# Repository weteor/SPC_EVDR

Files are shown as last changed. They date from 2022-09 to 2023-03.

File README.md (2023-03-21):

# SPC EVDR
38 key orthogonl keyboard w/ offset spacebar

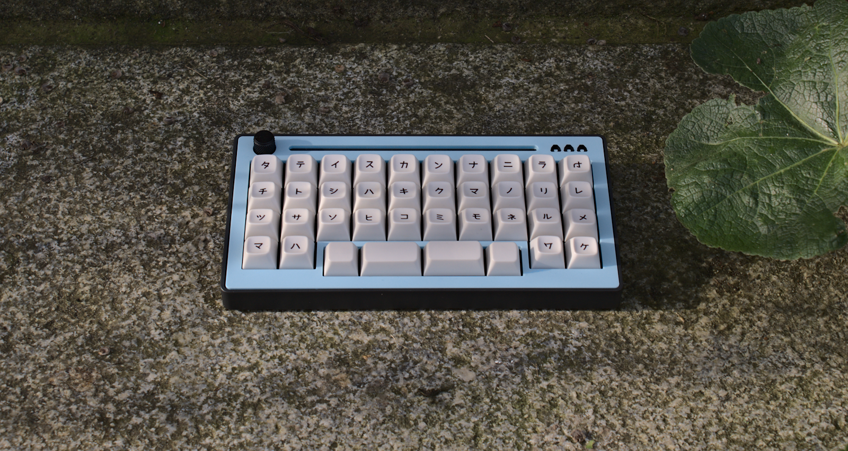
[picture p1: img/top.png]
top


## Features

- MX w/ hotswap
- encoder (12 mm knob diameter)
- OLED
- Bluetooth and USB connection
- case with optional acrylic accents
- case files are supplied (stl, dxf, as well as the freecad files)
- ZMK firmware support ( on Seeed Xiao SAMD21 or Seeed Xiao BLE )
- QMK firmware support ( on Seeed Xiao RP2040 )
- completely open source, permissive license

## Want one?
All production files you need to build your own board can be found [here](./prod).

Please see the [build instruction](prod/build_guide.md) for a more detailed listing of all things needed.

Gerber files as well as files needed for 3d printing are provided. Please note that the case design that supports the acryl layin may not be SLN printable. Please print them either in resin or nylon. I've used JLCPCBs printing service (black resin) and it turned out very good, so maybe take a look at that option.

### firmware 
The SPC EVDR uses ZMK firmware.

If you prefer the github workflow, you can find the zmk config [here](https://github.com/weteor/SPC_EVDR-Config).

## the rest
Everything in this repository is free to use however you might see fit. If you want to support me and my projects, please consider linking back to this repository if you build/change/use anything. 

If you would like to send me a tip, you could do it [here](https://ko-fi.com/weteor) (Please don't feel like you have to).

### some more images
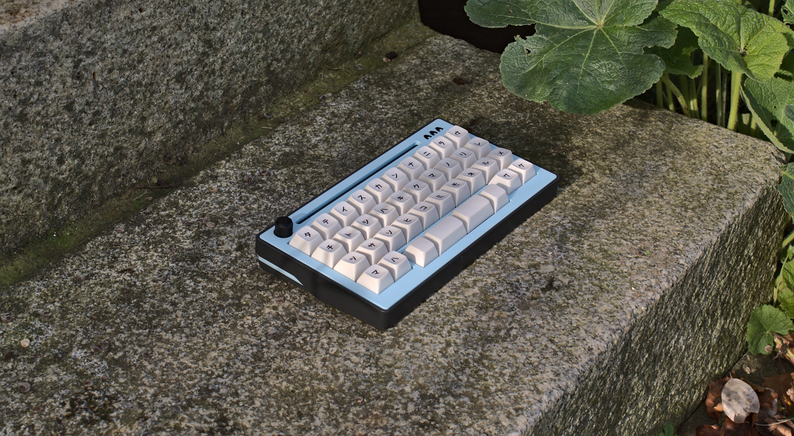
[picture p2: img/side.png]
side


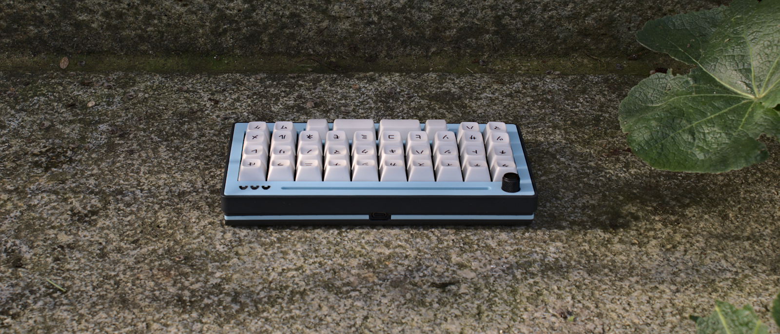
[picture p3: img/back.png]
back


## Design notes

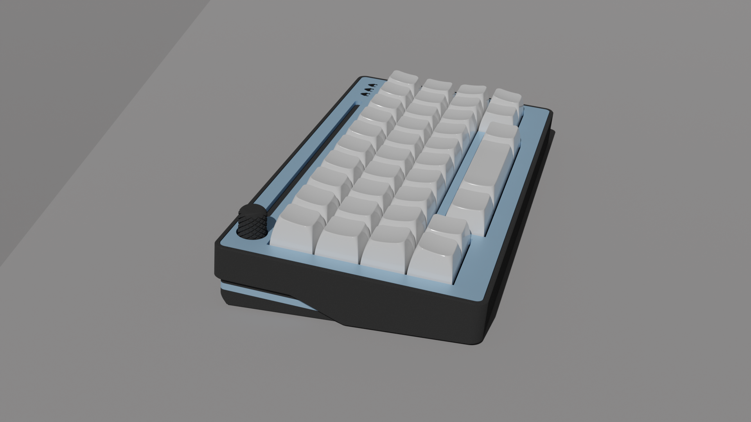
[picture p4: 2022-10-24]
img/side_knob.png

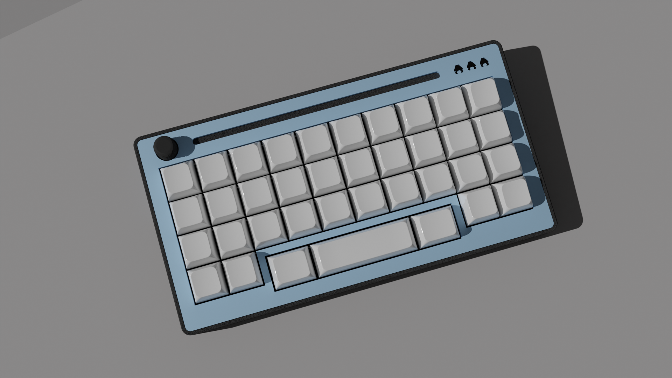
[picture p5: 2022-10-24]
img/top_knob.png

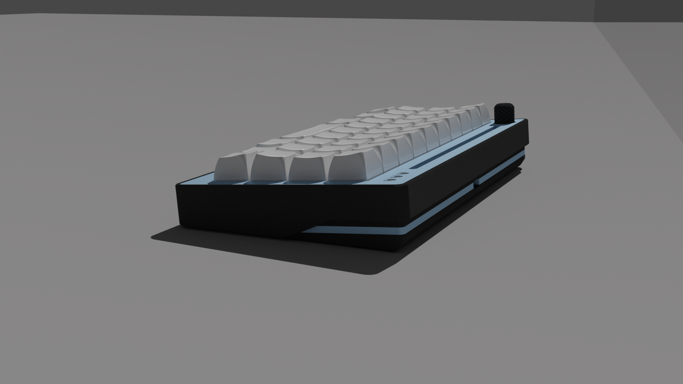
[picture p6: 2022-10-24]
img/backRight.png

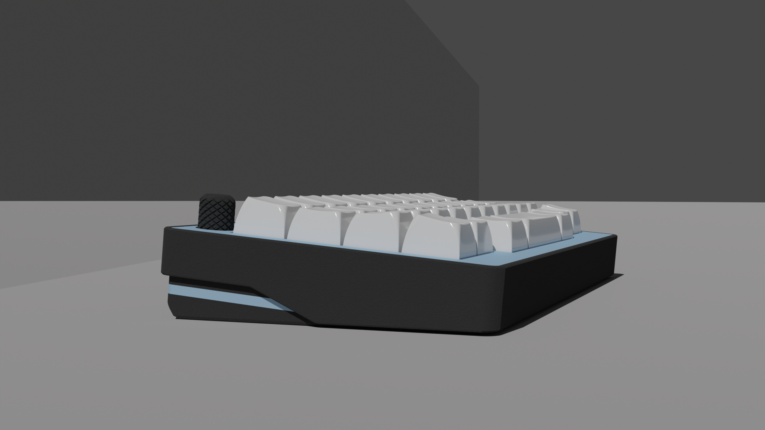
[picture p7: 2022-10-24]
img/side_knob_1.png

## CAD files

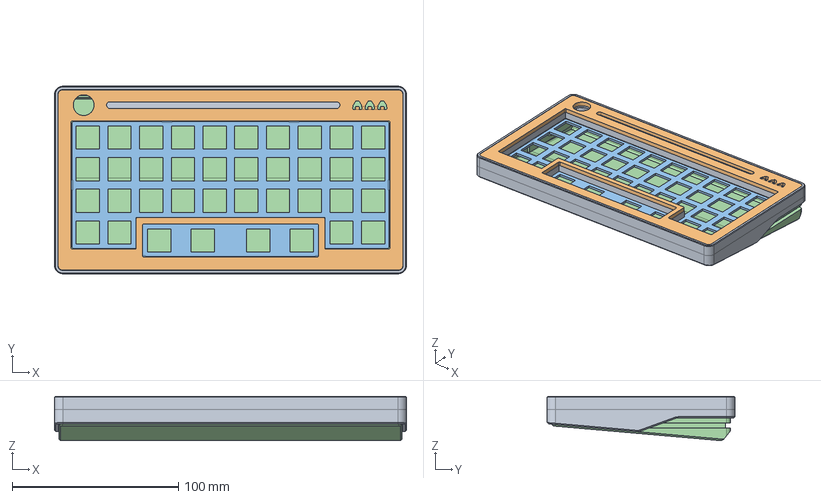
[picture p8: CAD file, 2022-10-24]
cad/case.FCStd
211.5 x 112.7 x 26.6 mm
Case
Acryl
Plate
bottomCase

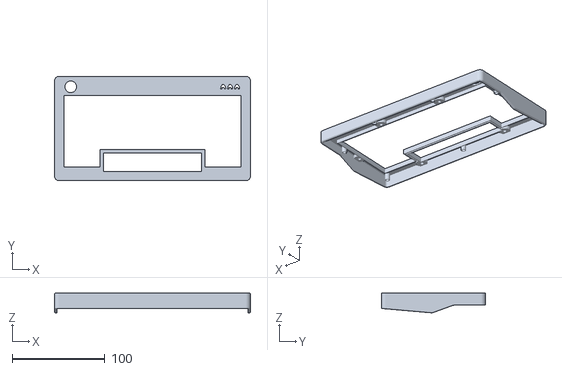
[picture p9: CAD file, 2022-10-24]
prod/Case/case_top_with_insert.stl
211.5 x 112.7 x 21.2

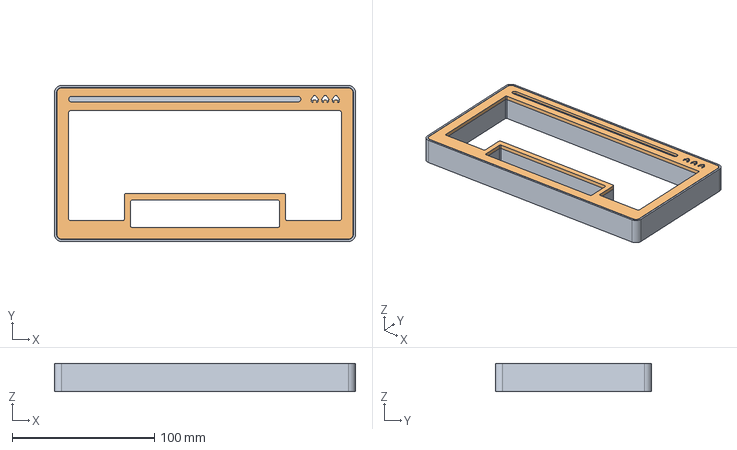
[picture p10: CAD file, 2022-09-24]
cad/platecase.FCStd
211.5 x 109.7 x 20.0 mm
Case

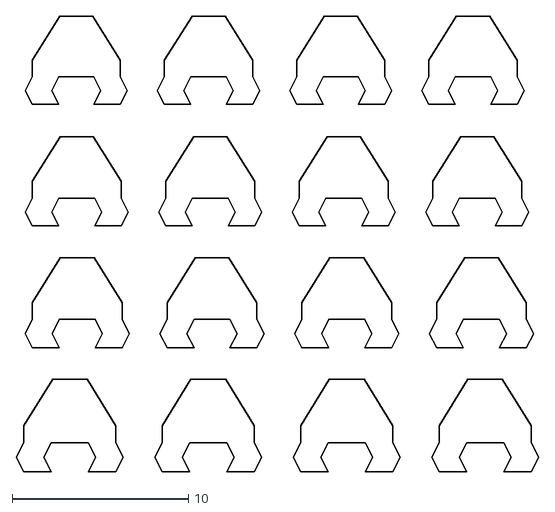
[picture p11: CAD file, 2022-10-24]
prod/Case/case_inveader_cover_cut.dxf
29.6 x 25.8

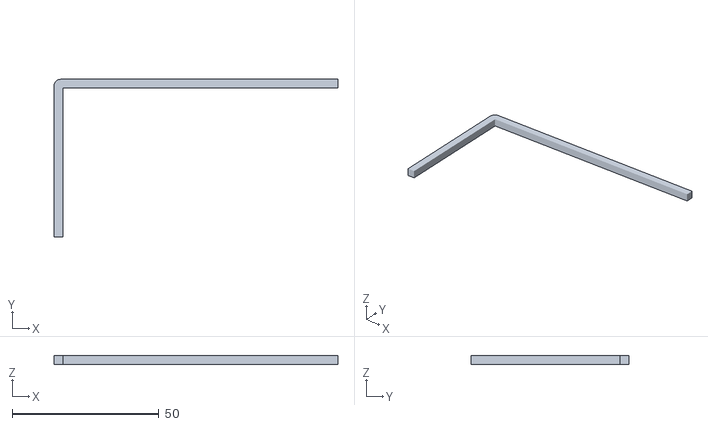
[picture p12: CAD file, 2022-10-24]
prod/Case/case_bottom_insert_left_printed.stl
96.8 x 53.7 x 3.00

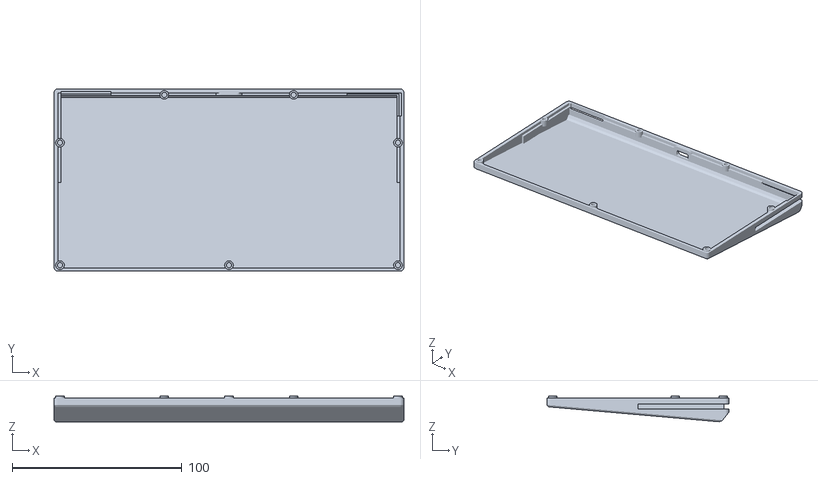
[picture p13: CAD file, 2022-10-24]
prod/Case/case_bottom.stl
206.2 x 107.4 x 15.1

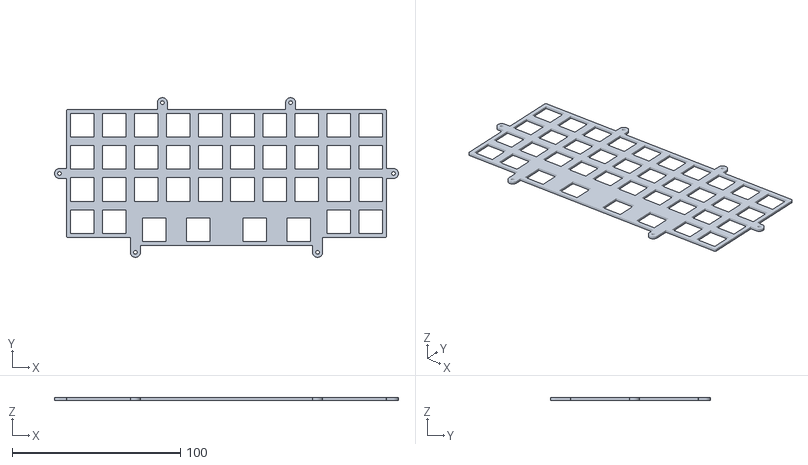
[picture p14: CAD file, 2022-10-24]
prod/Case/plate_1u_1.75u_1.75u_1u.stl
204.5 x 95.0 x 1.60

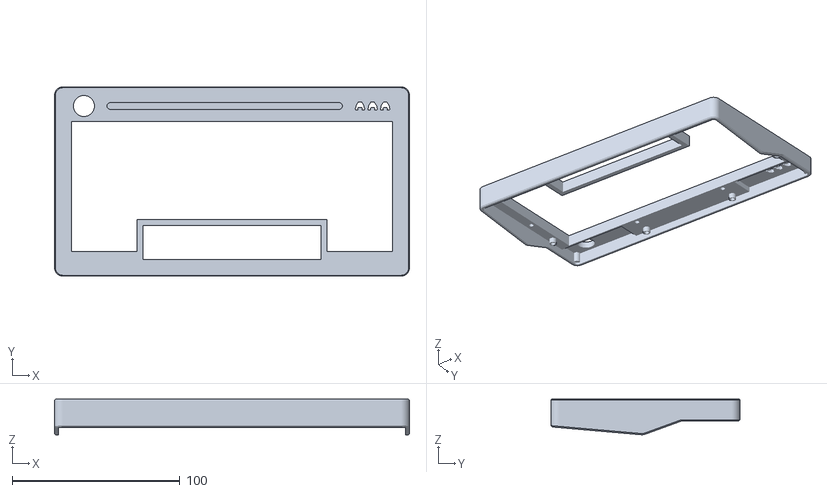
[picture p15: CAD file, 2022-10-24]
prod/Case/case_top_no_insert.stl
211.5 x 112.7 x 21.2

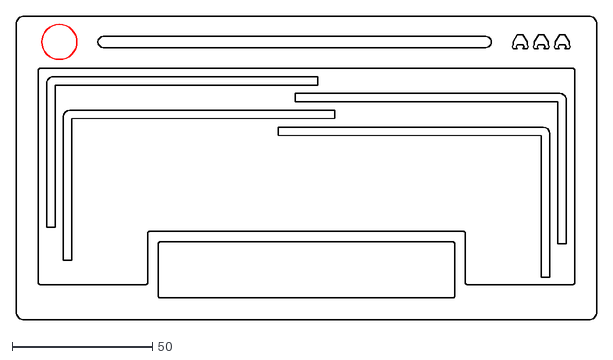
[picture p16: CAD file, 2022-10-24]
prod/Case/case_top_bottom_inserts_cut.dxf
207.2 x 108.4

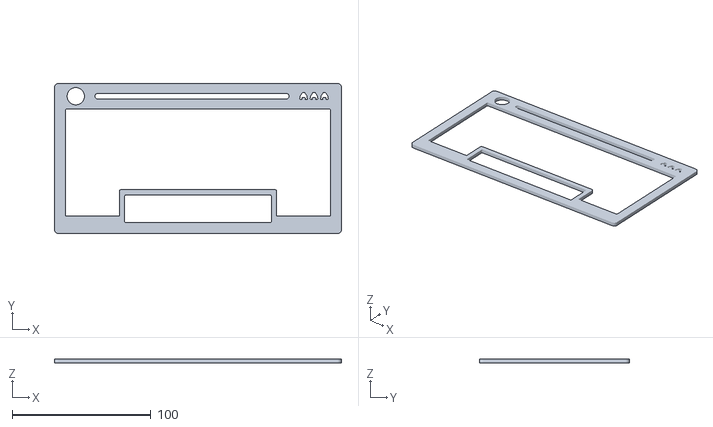
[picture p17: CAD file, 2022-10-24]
prod/Case/case_top_insert_printed.stl
207.2 x 108.4 x 3.00

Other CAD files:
prod/Case/case_bottom_insert_right_printed.stl

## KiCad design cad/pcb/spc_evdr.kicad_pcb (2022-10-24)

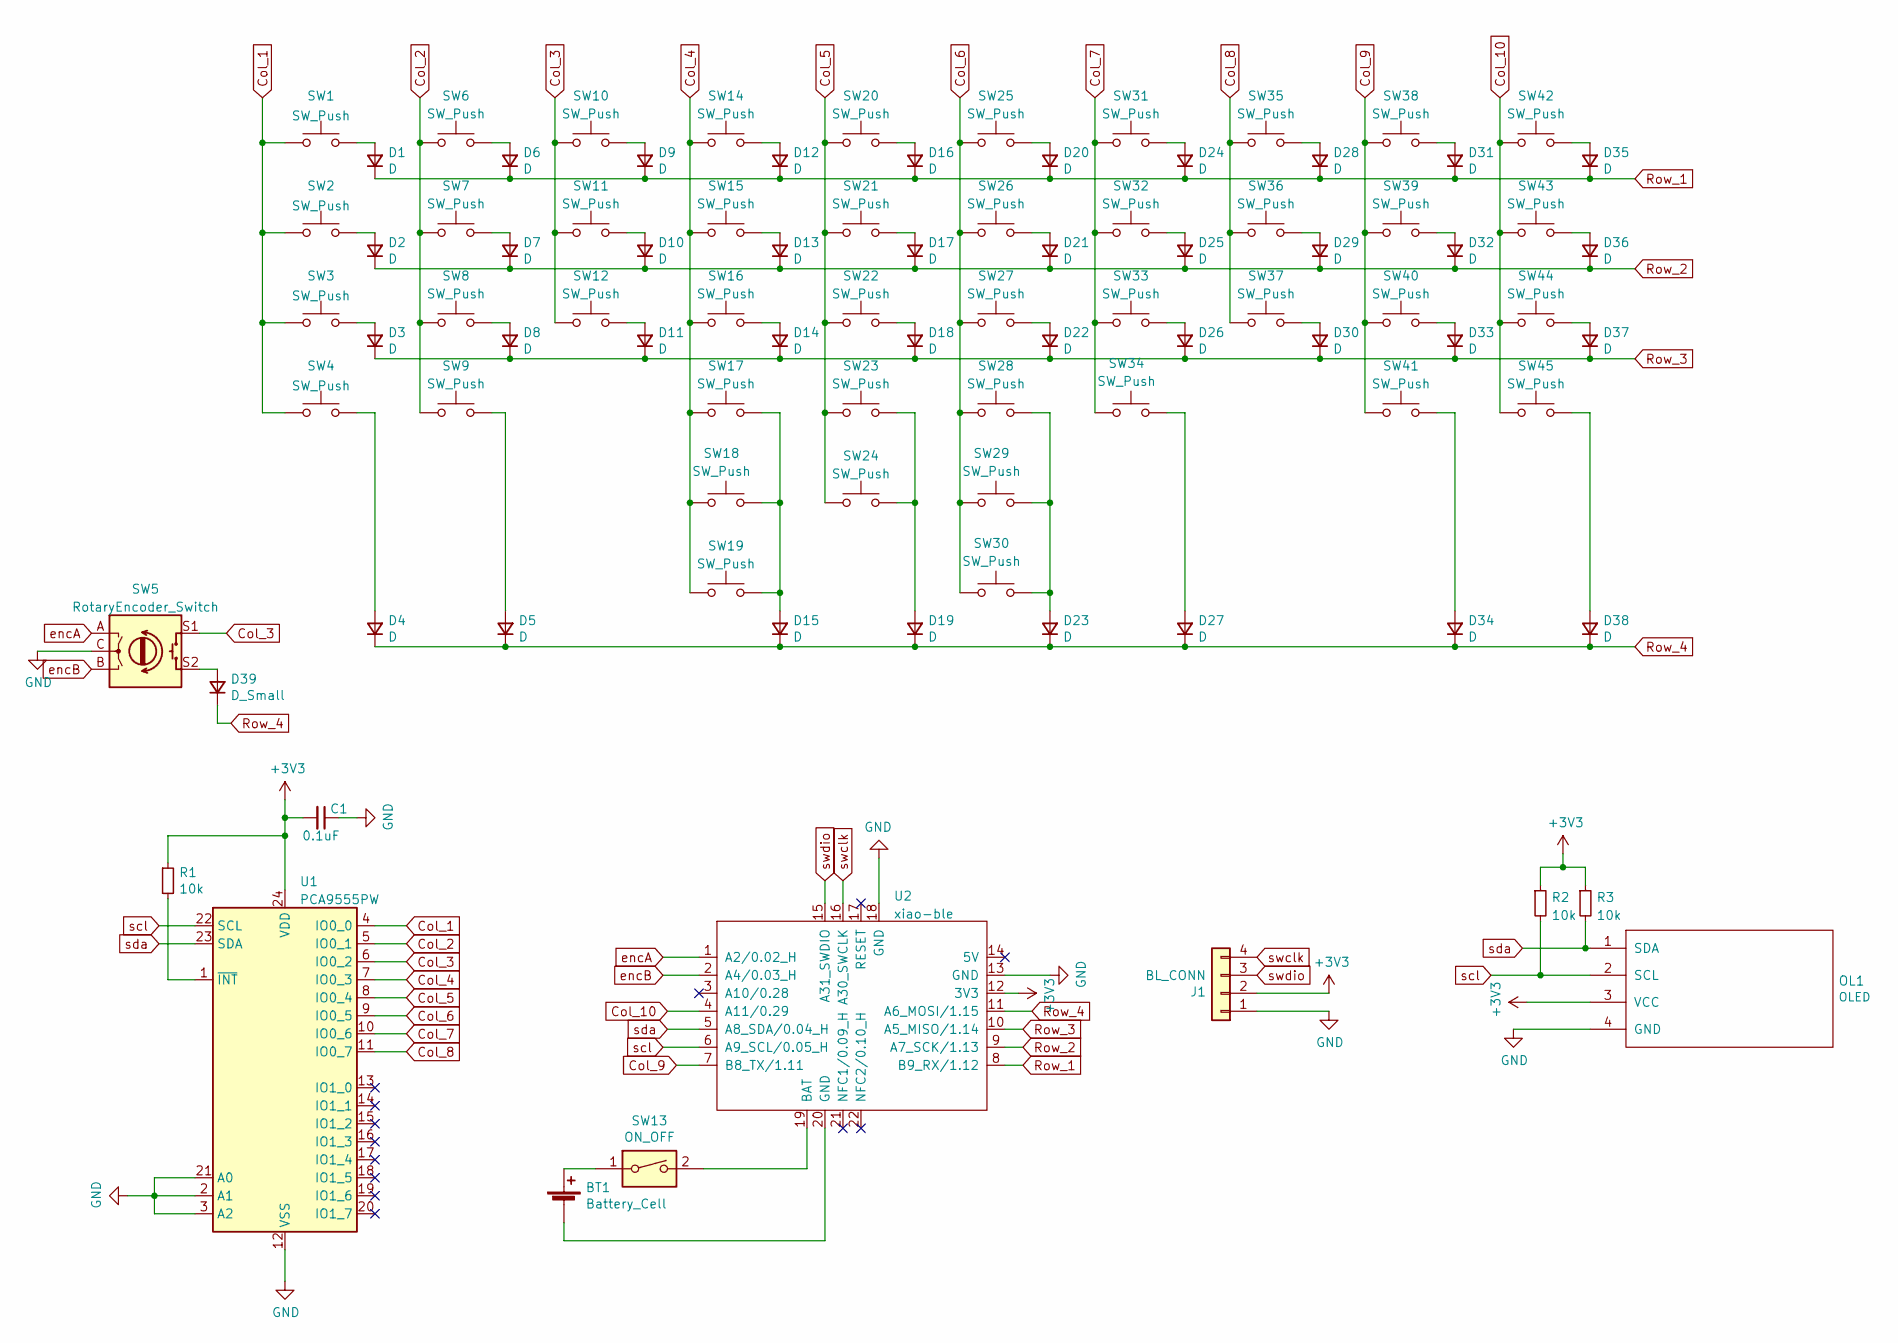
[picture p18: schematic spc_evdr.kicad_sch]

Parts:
BT1: Battery_Cell; Molex_PicoBlade_53048-0210_1x02_P1.25mm_Horizontal
C1: 0.1uF; C_0805_2012Metric
D1, D2, D3, D4, D5, D6, D7, D8, D9, D10, D11, D12, D13, D14, D15, D16, D17, D18, D19, D20, D21, D22, D23, D24, D25, D26, D27, D28, D29, D30, D31, D32, D33, D34, D35, D36, D37, D38: D; D_SOD-123
D39: D_Small; D_SOD-123
J1: BL_CONN; PinHeader_1x04_P2.54mm_Vertical
OL1: OLED; OLED_1side
R1, R2, R3: 10k; R_0805_2012Metric
SW1, SW2, SW3, SW4, SW6, SW7, SW8, SW9, SW10, SW11, SW12, SW14, SW15, SW16, SW17, SW20, SW21, SW22, SW25, SW26, SW27, SW31, SW32, SW33, SW34, SW35, SW36, SW37, SW38, SW39, SW40, SW41, SW42, SW43, SW44, SW45: SW_Push; CherryMX_Hotswap
SW5: RotaryEncoder_Switch; RotaryEncoder_Alps_EC11E-Switch_Vertical_H20mm
SW13: ON_OFF; switch_MSK-12C02_smd
SW18, SW29: SW_Push; CherryMX_Hotswap_1.25u
SW19, SW30: SW_Push; CherryMX_Hotswap_2.25u_stabs
SW23, SW28: SW_Push; CherryMX_Hotswap_1.75u
SW24: SW_Push; CherryMX_Hotswap_3u_stabs
U1: PCA9555PW; TSSOP-24_4.4x7.8mm_P0.65mm
U2: xiao-ble; xiao-ble-smd-cutout

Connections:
+3V3: C1.2, J1.2, OL1.3 (VCC), R1.1, R2.1, R3.1, U1.24 (VDD), U2.12 (3V3)
Col_1: SW1.1, SW2.1, SW3.1, SW4.1, U1.4 (IO0_0)
Col_2: SW6.1, SW7.1, SW8.1, SW9.1, U1.5 (IO0_1)
Col_3: SW5.S1, SW10.1, SW11.1, SW12.1, U1.6 (IO0_2)
Col_4: SW14.1, SW15.1, SW16.1, SW17.1, SW18.1, SW19.1, U1.7 (IO0_3)
Col_5: SW20.1, SW21.1, SW22.1, SW23.1, SW24.1, U1.8 (IO0_4)
Col_6: SW25.1, SW26.1, SW27.1, SW28.1, SW29.1, SW30.1, U1.9 (IO0_5)
Col_7: SW31.1, SW32.1, SW33.1, SW34.1, U1.10 (IO0_6)
Col_8: SW35.1, SW36.1, SW37.1, U1.11 (IO0_7)
Col_9: SW38.1, SW39.1, SW40.1, SW41.1, U2.7 (B8_TX/1.11)
Col_10: SW42.1, SW43.1, SW44.1, SW45.1, U2.4 (A11/0.29)
GND: C1.1, J1.1, OL1.4 (GND), SW5.C, U1.2 (A1), U1.3 (A2), U1.12 (VSS), U1.21 (A0), U2.13 (GND), U2.18 (GND)
unnamed: BT1.1 (+), SW13.1
unnamed: BT1.2 (-), U2.20 (GND)
unnamed: D1.2 (A), SW1.2
unnamed: D2.2 (A), SW2.2
unnamed: D3.2 (A), SW3.2
unnamed: D4.2 (A), SW4.2
unnamed: D5.2 (A), SW9.2
unnamed: D6.2 (A), SW6.2
unnamed: D7.2 (A), SW7.2
unnamed: D8.2 (A), SW8.2
unnamed: D9.2 (A), SW10.2
unnamed: D10.2 (A), SW11.2
unnamed: D11.2 (A), SW12.2
unnamed: D12.2 (A), SW14.2
unnamed: D13.2 (A), SW15.2
unnamed: D14.2 (A), SW16.2
unnamed: D15.2 (A), SW17.2, SW18.2, SW19.2
unnamed: D16.2 (A), SW20.2
unnamed: D17.2 (A), SW21.2
unnamed: D18.2 (A), SW22.2
unnamed: D19.2 (A), SW23.2, SW24.2
unnamed: D20.2 (A), SW25.2
unnamed: D21.2 (A), SW26.2
unnamed: D22.2 (A), SW27.2
unnamed: D23.2 (A), SW28.2, SW29.2, SW30.2
unnamed: D24.2 (A), SW31.2
unnamed: D25.2 (A), SW32.2
unnamed: D26.2 (A), SW33.2
unnamed: D27.2 (A), SW34.2
unnamed: D28.2 (A), SW35.2
unnamed: D29.2 (A), SW36.2
unnamed: D30.2 (A), SW37.2
unnamed: D31.2 (A), SW38.2
unnamed: D32.2 (A), SW39.2
unnamed: D33.2 (A), SW40.2
unnamed: D34.2 (A), SW41.2
unnamed: D35.2 (A), SW42.2
unnamed: D36.2 (A), SW43.2
unnamed: D37.2 (A), SW44.2
unnamed: D38.2 (A), SW45.2
unnamed: D39.2 (A), SW5.S2
unnamed: R1.2, U1.1 (~INT)
unnamed: SW13.2, U2.19 (BAT)
Row_1: D1.1 (K), D6.1 (K), D9.1 (K), D12.1 (K), D16.1 (K), D20.1 (K), D24.1 (K), D28.1 (K), D31.1 (K), D35.1 (K), U2.8 (B9_RX/1.12)
Row_2: D2.1 (K), D7.1 (K), D10.1 (K), D13.1 (K), D17.1 (K), D21.1 (K), D25.1 (K), D29.1 (K), D32.1 (K), D36.1 (K), U2.9 (A7_SCK/1.13)
Row_3: D3.1 (K), D8.1 (K), D11.1 (K), D14.1 (K), D18.1 (K), D22.1 (K), D26.1 (K), D30.1 (K), D33.1 (K), D37.1 (K), U2.10 (A5_MISO/1.14)
Row_4: D4.1 (K), D5.1 (K), D15.1 (K), D19.1 (K), D23.1 (K), D27.1 (K), D34.1 (K), D38.1 (K), D39.1 (K), U2.11 (A6_MOSI/1.15)
encA: SW5.A, U2.1 (A2/0.02_H)
encB: SW5.B, U2.2 (A4/0.03_H)
scl: OL1.2 (SCL), R2.2, U1.22 (SCL), U2.6 (A9_SCL/0.05_H)
sda: OL1.1 (SDA), R3.2, U1.23 (SDA), U2.5 (A8_SDA/0.04_H)
swclk: J1.4, U2.16 (A30_SWCLK)
swdio: J1.3, U2.15 (A31_SWDIO)

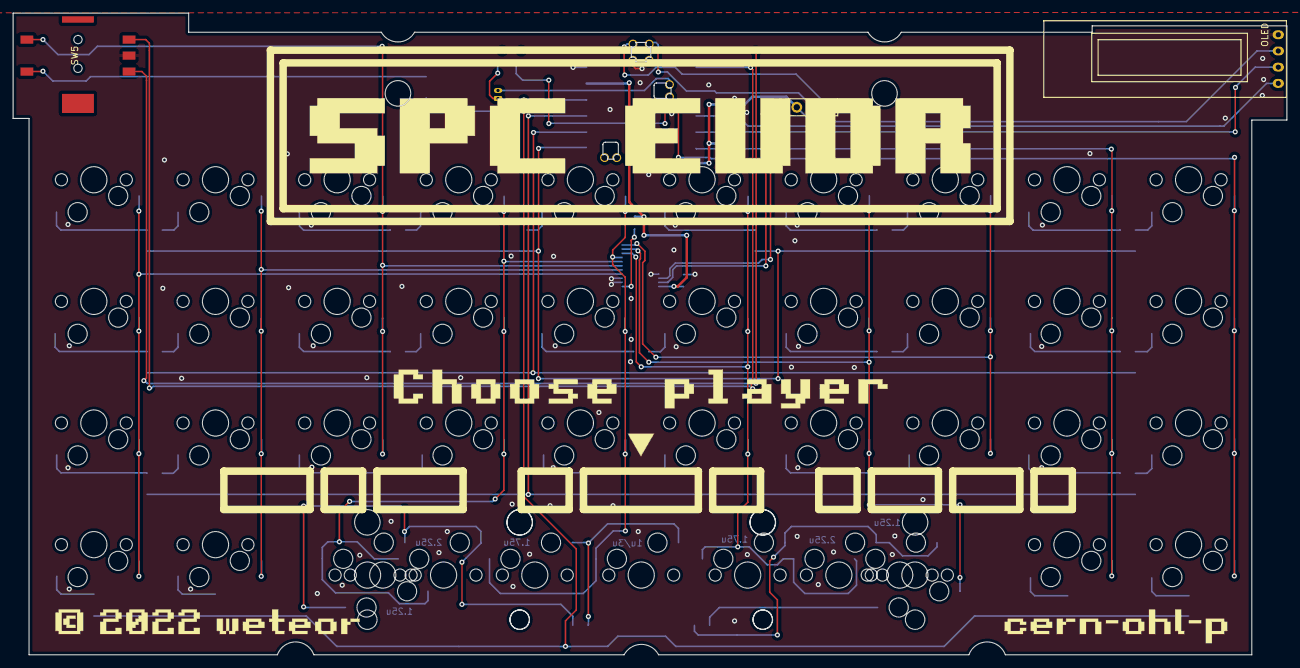
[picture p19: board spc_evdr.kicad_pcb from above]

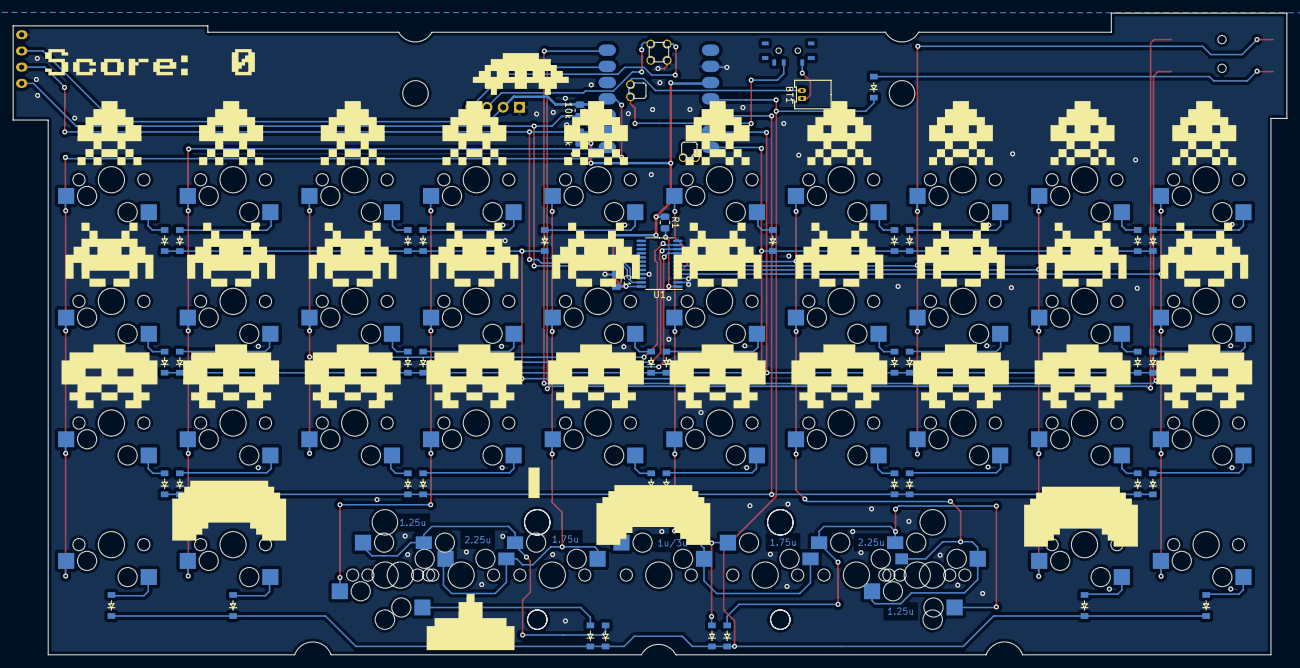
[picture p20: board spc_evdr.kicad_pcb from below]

Board: 2 copper layers, 199.5 x 100.5 mm, 93 parts (47 on the bottom side), 65 nets.

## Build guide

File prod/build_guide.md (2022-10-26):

# build instructions

## what do you need?

#### parts
| # | name | comments |
|---|---|---|
| 1 | main PCB | [gerber files](PCB) |
| 1 | Seeed Xiao (optional BLE) | Controller board |
| 3 | R - 0805 - 10k | resistor |
| 1 | C - 0805 - 100nF | capacitor |
| 1 | PCA9555PW | IO Expander |
| 38 | 1N4148 - SOD-123 | diodes |
| 38-41 | HS Sockets | MX hotswap sockets |
| 1 | ec11 12mm | encoder |
| 1 | 0.91'' 128x32px | OLED module |
| 1 | MSK-12C02 | power switch |
| 1 | JST GSH 1.25mm pitch | battery connector, 2pin (optional) |
| 1 | 3.7V LiPo | battery (optional) |
| 1 | case top | [case files](prod/case) |
| 1 | case botom | [case files](prod/case) |
| 1 | acryl inserts | [case files](prod/case) optional |
| 6 | heat inserts m2 | |
| 6 | M2 screws - 6mm | |
| 14 | magnets | 3x3 cylindrical N35 |
| 38 | switches | MX |
| | keycaps | |

#### tools
- soldering iron
- 
## build 
### pcb
- connect the Xiao, enter bootloader by double clicking the reset button, flash firmware and check if it is recognized correctly.
- solder the Xiao to the pcb
- solder IO expander, diodes, capacitor and resistors to the pcb.
- check if all switches work by shorting the pads.
- If everything works, solder everything except the OLED to the pcb

### case
- add heat inserts (either by melting them in, or file the hole a bit larger and just press them in)
- try if magnets fit the holes tightly. Add a bit of superglue if they don't stay in place. Make sure the polarity is correct!
- insert some switches to the plate edges so the pcb stays in place. Add the OLED, don't solder just yet. Alignt the plate and check if the OLED is aligned to the invader cutouts. You should be able to activate the OLED without soldering it if you angle it a bit. If it is not aligned, use some sharp/flat knife to loose the display a bit from it's pcb and reposition it.
- fix the plate with a few screws, the oled should rest on the top case, solder the OLED.
- add remaining switches
- screw in the plate
- put together both case parts.
- (optional) add acryl parts. If they don't stay in place use some double sided tape and/or superglue to keep them in place

ENJOY

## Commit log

2022-09-23 add mockup case and plate
    [platecase.FCStd]
2022-09-23 add opl kicad library
2022-09-24 add kicad files, finished functionally
    [spc_evdr.kicad_pcb, spc_evdr.kicad_sch]
2022-09-24 add border to case
    [platecase.FCStd]
2022-10-24 update pcb files
    [spc_evdr.kicad_pcb, spc_evdr.kicad_sch]
2022-10-24 update case cad files
    [case.FCStd]
2022-10-24 add pcb gerber files
2022-10-24 add case printing and cutting files
    [case_bottom.stl, case_bottom_insert_left_printed.stl, case_bottom_insert_right_printed.stl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]
